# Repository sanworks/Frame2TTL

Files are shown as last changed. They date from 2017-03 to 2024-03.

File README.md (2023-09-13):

# Frame2TTL
Hardware and software to capture discrete pixel intensity transitions from a small patch of an LCD screen. Transitions are reported as TTL pulses. This device is used to provide precise measurements of frame onset time in visual stimulus presentation

The bill of materials and other documentation is available at:
https://sites.google.com/site/frame2ttl

Frame2TTL is a product of Sanworks LLC, licensed under GPL v3.0 (see included license)
http://sanworks.io

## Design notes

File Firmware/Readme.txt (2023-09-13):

To compile for Frame2TTL v2 and newer, use the firmware in the Frame2TTL folder.
Configure the HARDWARE_VERSION macro to match your hardware version.

For Frame2TTL v1, use firmware in the Legacy folder.

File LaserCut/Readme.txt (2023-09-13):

Note: To be laser cut from 3mm clear acrylic sheet.

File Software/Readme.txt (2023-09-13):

Important note:
For Frame2TTL hardware v1, use software in the Legacy folder.

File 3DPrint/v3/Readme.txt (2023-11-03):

Build notes:

F2TTL_v3_PrintedParts_r1_0 and
F2TTL_v3_PrintedParts_r1_0_PressFitSensor
are designed for 3D-printing on an FDM machine.

In the PressFitSensor version, the sensor connects to the side mount arm with a loose friction fit instead of with tab locking, allowing it to be removed after assembly.

Material: Ultimaker CPE, ColorFabb XT or equivalent
Material color: Black
Nozzle width: 0.4mm
Ultimaker printer recommended. Use slicer settings from included Cura profile.

F2TTL_v3 contains 4 parts to print, and 1 model of the circuit board (colored black). Part names are noted in the design file.

Assembly notes:
-The PCB mount holds the sensor PCB. Press the PCB bottom into the bottom of the mount and bend the mount slightly until the PCB presses under the retaining edges. The PCB will be secure when the mount relaxes.

-The PCB mount snaps into the side arm with moderate pressure. Orient the PCB mount so that the sensor faces towards the arm.

-The rear arm has a socket for a captured nut and thumb screw. The rectangular extension of the side arm fits into the rectangular hole in the rear arm. The initial fit may be tight. Force the rear arm back and forth along the side arm ~20 times to achieve a good fit.

-The foot connects to the rear arm with the dowel pin. Align the holes and press the dowel pin from above until it mates with the narrow hole on the opposite side, securing the foot in place.

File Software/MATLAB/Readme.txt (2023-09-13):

IMPORTANT NOTE:
The Frame2TTL class in this folder supports hardware v2 or newer.
A class compatible with hardware v1 can be found in /Software/Legacy/

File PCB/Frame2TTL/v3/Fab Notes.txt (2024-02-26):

-Frame2TTL_v3_X_Sensor must be fabbed with board thickness = 0.6mm
-Frame2TTL_v3_X must be fabbed with board thickness = 1.6mm (standard)

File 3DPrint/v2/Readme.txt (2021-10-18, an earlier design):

Files are designed for 3D-printing on an FDM machine

Material: CPE, ColorFabb XT or equivalent
Nozzle width: 0.4mm
Ultimaker printer recommended. Use slicer settings from included Cura profile.

F2TTL_v2_ForIpad contains 2 parts to print, and 1 model of the board. The two parts press together to form a clip that gently mounts the sensor to the bottom edge of an Ipad screen (Adafruit Part# 1751). The first part must be slightly bent to insert the circuit board. Then, the first part presses into the second part.

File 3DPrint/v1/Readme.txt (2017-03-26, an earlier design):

The parts in Frame2TTL.skp should be printed by FDM with a 0.4mm nozzle.
Recommended: 30% infill, 1.6mm wall thickness

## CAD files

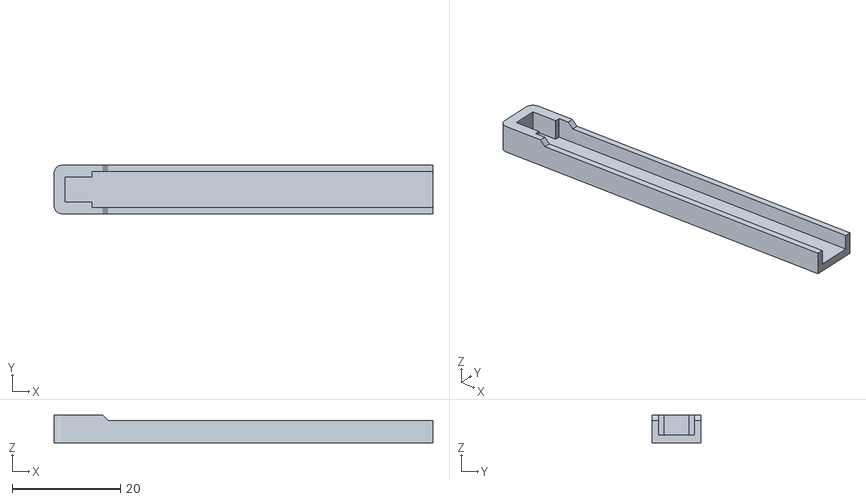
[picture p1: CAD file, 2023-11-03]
Sketchup/Frame2TTL1.stl
70.0 x 9.00 x 5.10

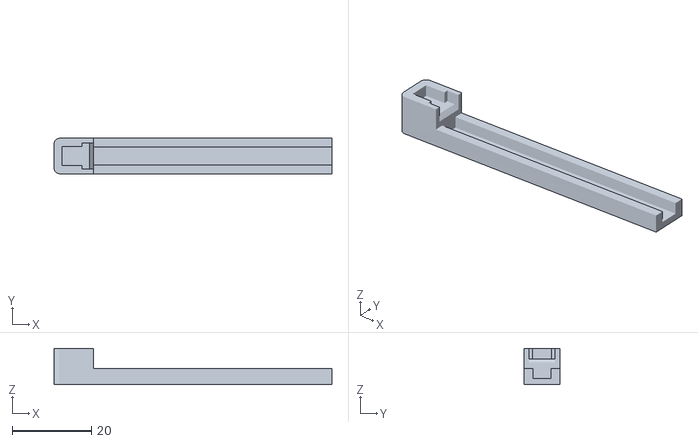
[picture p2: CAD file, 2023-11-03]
Sketchup/Frame2TTL2.stl
70.0 x 9.00 x 9.11

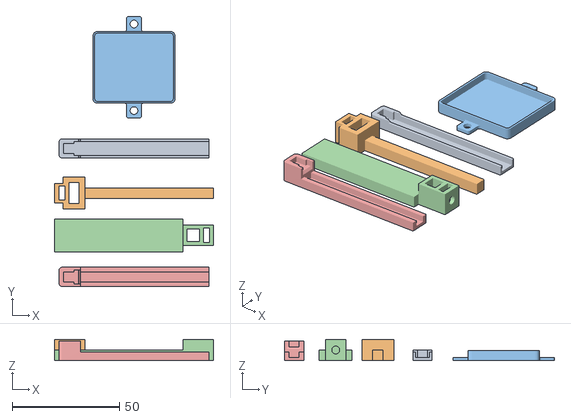
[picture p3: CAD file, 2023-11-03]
Sketchup/Frame2TTLAll.stl
74.3 x 126.0 x 10.0
"Frame2TTLAll" x 5

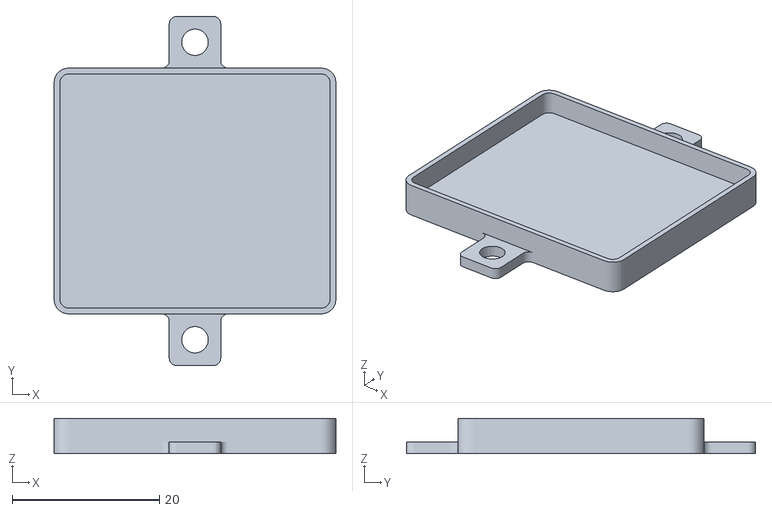
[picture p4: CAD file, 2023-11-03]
Sketchup/Frame2TTL5.stl
38.3 x 47.4 x 4.80

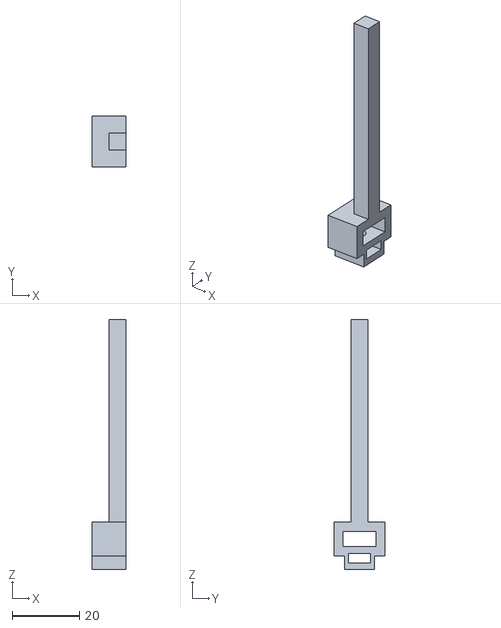
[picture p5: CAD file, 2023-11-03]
Sketchup/Frame2TTL4.stl
10.0 x 15.0 x 74.1

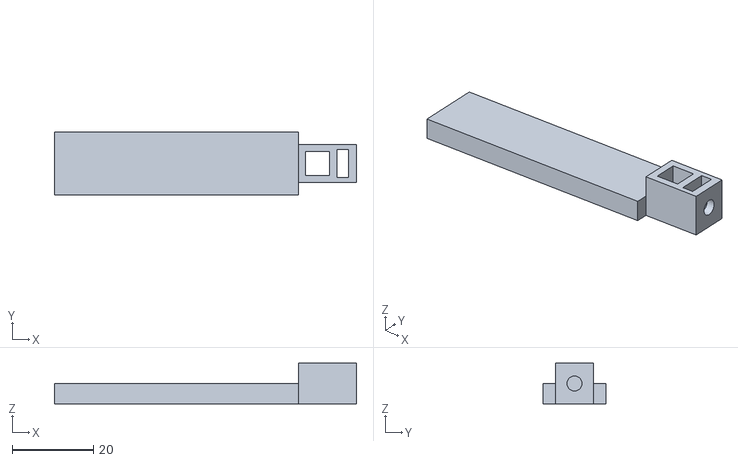
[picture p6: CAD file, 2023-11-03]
Sketchup/Frame2TTL3.stl
74.3 x 15.4 x 10.0

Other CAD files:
3DPrint/v1/Frame2TTL.skp
3DPrint/v1/PCB_UnderGuard.skp
3DPrint/v2/F2TTL_V2_ForIpad.skp
3DPrint/v3/Frame2TTL_v3_PrintedParts_r1_0.skp
3DPrint/v3/Frame2TTL_v3_PrintedParts_r1_0_PressFitSensor.skp
3DPrint/v3/Frame2TTL_v3_PrintedParts_r1_1.skp
LaserCut/Frame2TTL_v3_LaserCutParts_r1_0.skp

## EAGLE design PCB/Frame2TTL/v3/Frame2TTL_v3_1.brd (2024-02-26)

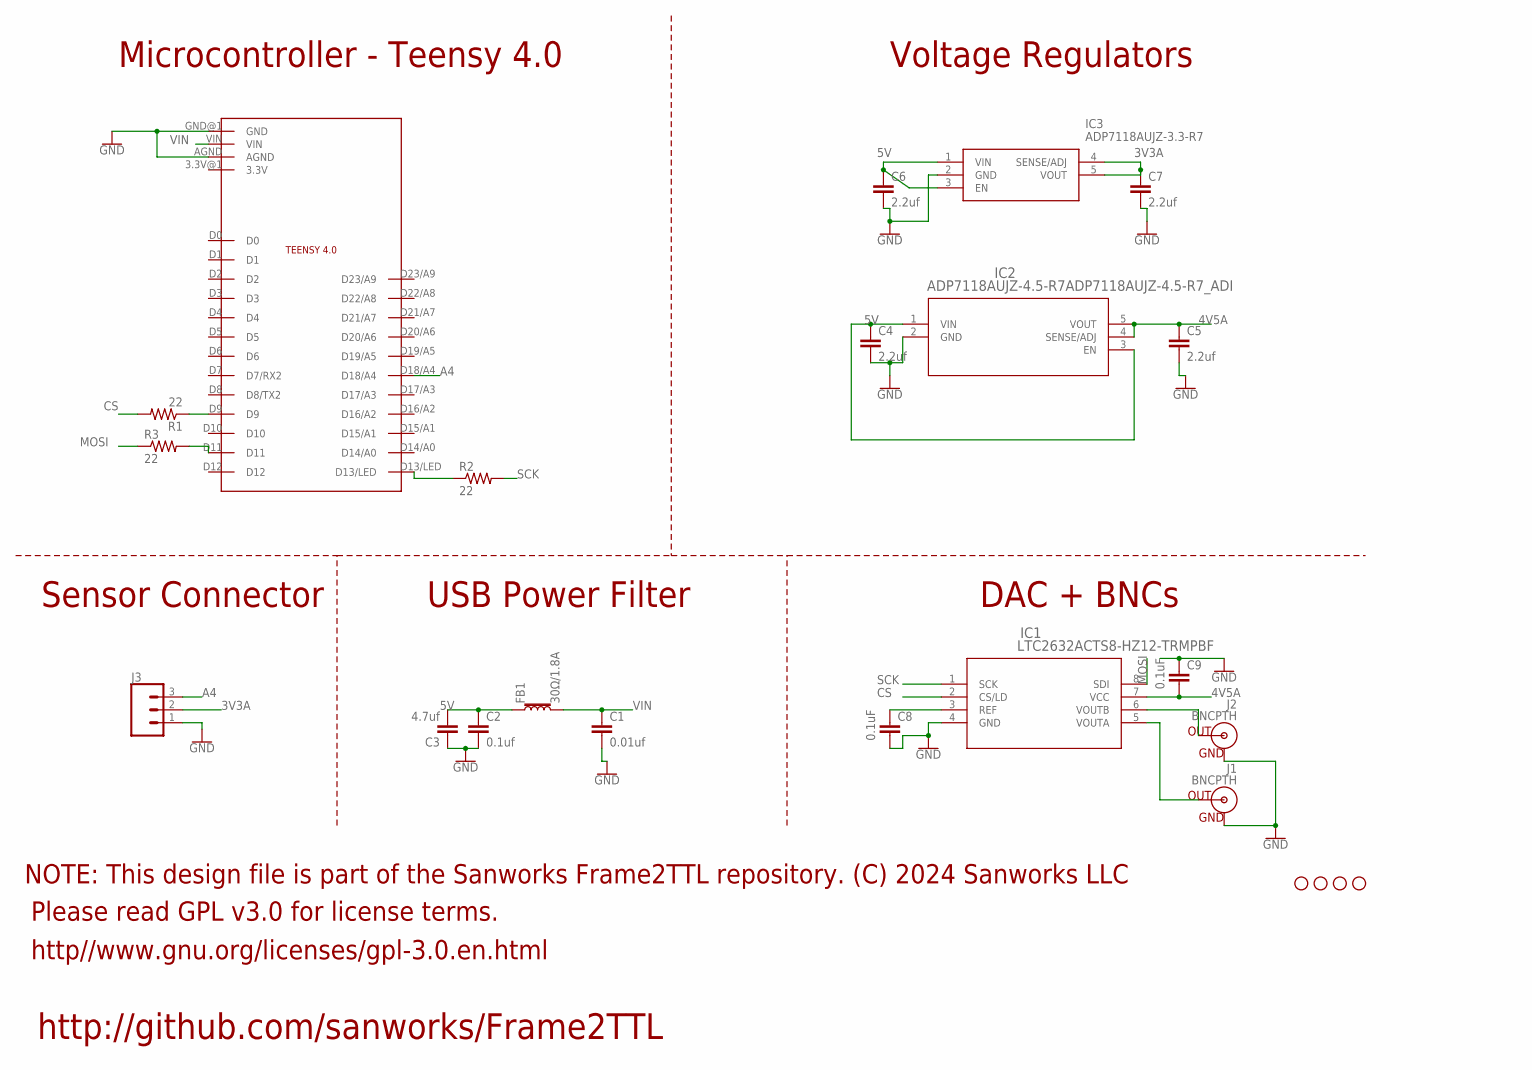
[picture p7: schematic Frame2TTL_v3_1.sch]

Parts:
C1: 0.01uf; 0805
C2: 0.1uf; 0805
C3: 4.7uf; 1206@2
C4, C5, C6, C7: 2.2uf; 0805
C8, C9: 0.1uF; 0805
FB1: 30Ω/1.8A; 0603
H1, H2, H3, H4: STAND-OFF
IC1: LTC2632ACTS8-HZ12-TRMPBF; TSOT-23-8_1P625X2P9_ADI
IC2: ADP7118AUJZ-4.5-R7ADP7118AUJZ-4.5-R7_ADI; ADP7118AUJZ-4.5-R7_ADI
IC3: ADP7118AUJZ-3.3-R7; SOT95P280X100-5N
J1, J2: BNCPTH; BNC
J3: CONN_03LOCK; 1X03_LOCK
MC1: TEENSY4.0_SIMPLE_NO_VUSB
R1, R2, R3: 22; R0805

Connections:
3V3A: C7.1, IC3.4 (SENSE/ADJ), IC3.5 (VOUT), J3.2
4V5A: C5.1, C9.2, IC1.7 (VCC), IC2.4 (SENSE/ADJ), IC2.5 (VOUT)
5V: C2.1, C3.2, C4.1, C6.1, FB1.1, IC2.1 (VIN), IC2.3 (EN), IC3.1 (VIN), IC3.3 (EN)
A4: J3.3, MC1.D18/A4
CS: IC1.2 (CS/LD), R1.2
GND: C1.2, C2.2, C3.1, C4.2, C5.2, C6.2, C7.2, C8.2, C9.1, IC1.4 (GND), IC2.2 (GND), IC3.2 (GND), J1.GND, J2.GND, J3.1, MC1.AGND, MC1.GND@1 (GND)
MOSI: IC1.8 (SDI), R3.1
unnamed: MC1.D11, R3.2
unnamed: MC1.D9, R1.1
unnamed: MC1.D13/LED, R2.1
unnamed: IC1.5 (VOUTA), J1.S (OUT)
unnamed: IC1.6 (VOUTB), J2.S (OUT)
unnamed: C8.1, IC1.3 (REF)
SCK: IC1.1 (SCK), R2.2
VIN: C1.1, FB1.2, MC1.VIN

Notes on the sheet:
Please read GPL v3.0 for license terms.
NOTE: This design file is part of the Sanworks Frame2TTL repository. (C) 2024 Sanworks LLC
http://github.com/sanworks/Frame2TTL
http//www.gnu.org/licenses/gpl-3.0.en.html
Microcontroller - Teensy 4.0
Voltage Regulators
USB Power Filter
Sensor Connector
DAC + BNCs

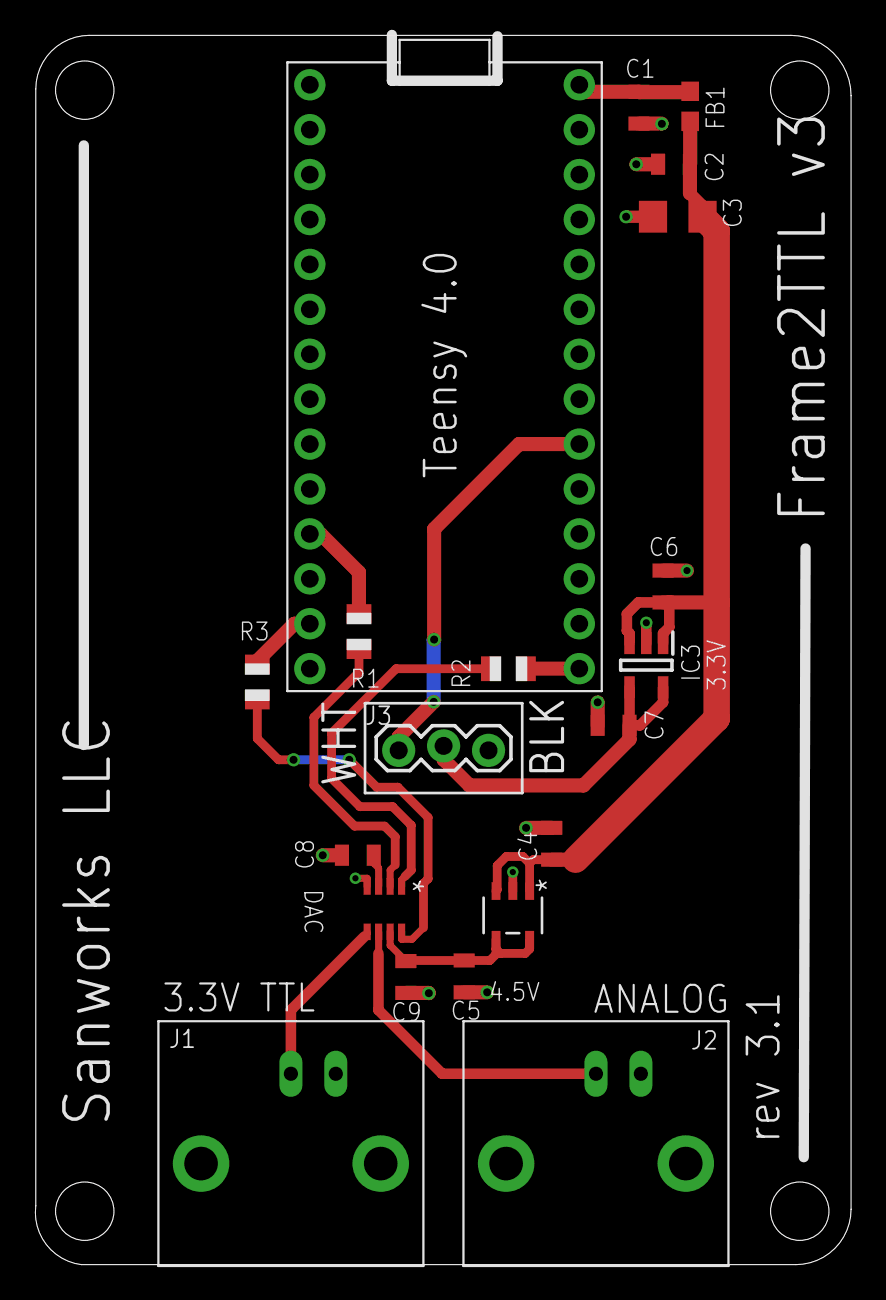
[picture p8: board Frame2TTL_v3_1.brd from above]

Board: 2 copper layers, 46.1 x 69.5 mm, 24 parts (0 on the bottom side), 15 nets.

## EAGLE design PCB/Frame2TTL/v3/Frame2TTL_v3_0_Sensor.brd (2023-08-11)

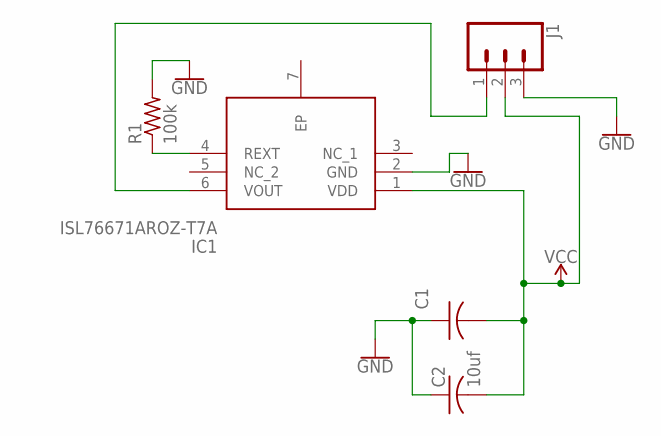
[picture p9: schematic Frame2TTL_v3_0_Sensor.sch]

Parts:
C1: 0.1uf; C0603K
C2: 10uf; C0805K
IC1: ISL76671AROZ-T7A; SON65P210X200X80-7N
J1: CONN_03LOCK; 1X03_LOCK
R1: 100k; R0805

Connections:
GND: C1.1, C2.1, IC1.2 (GND), J1.3, R1.2
unnamed: IC1.6 (VOUT), J1.1
unnamed: IC1.4 (REXT), R1.1
VCC: C1.2, C2.2, IC1.1 (VDD), J1.2

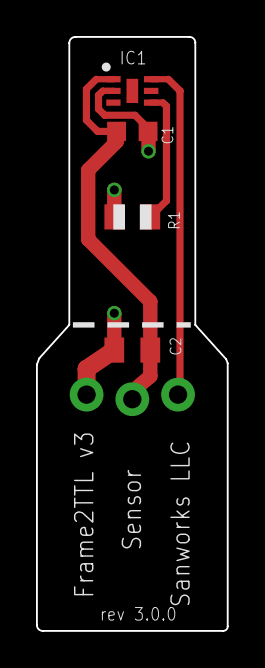
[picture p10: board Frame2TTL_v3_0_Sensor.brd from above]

Board: 2 copper layers, 10.6 x 33.0 mm, 5 parts (1 on the bottom side), 4 nets.

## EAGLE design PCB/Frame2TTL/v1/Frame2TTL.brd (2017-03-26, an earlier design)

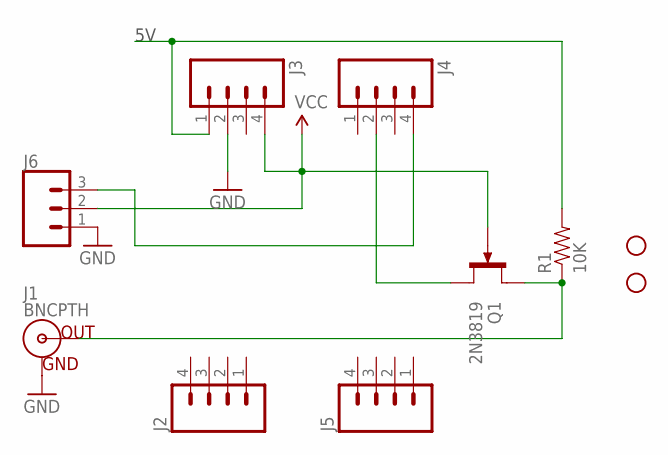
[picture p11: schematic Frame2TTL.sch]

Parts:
H1, H2: STAND-OFFTIGHT; STAND-OFF-TIGHT
J1: BNCPTH; BNC
J2, J3, J4, J5: M04PTH; 1X04
J6: CONN_03SCREW_LOCK; SCREWTERMINAL-3.5MM-3_LOCK.007S
Q1: 2N3819; TO92F
R1: 10K; AXIAL-0.3

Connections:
5V: J3.1, R1.P$2 (2)
GND: J1.GND, J3.2, J6.1
unnamed: J4.4, J6.3
unnamed: J4.2, Q1.S
unnamed: J1.S (OUT), Q1.D, R1.P$1 (1)
VCC: J3.4, J6.2, Q1.G

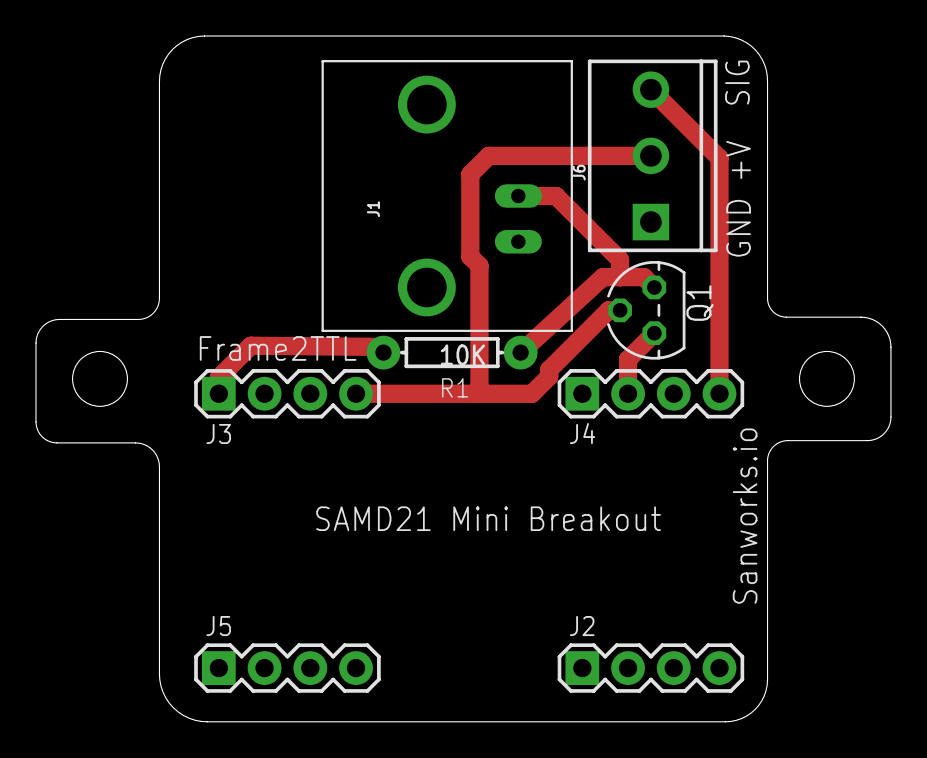
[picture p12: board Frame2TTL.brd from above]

Board: 2 copper layers, 47.5 x 38.1 mm, 10 parts (0 on the bottom side), 6 nets.

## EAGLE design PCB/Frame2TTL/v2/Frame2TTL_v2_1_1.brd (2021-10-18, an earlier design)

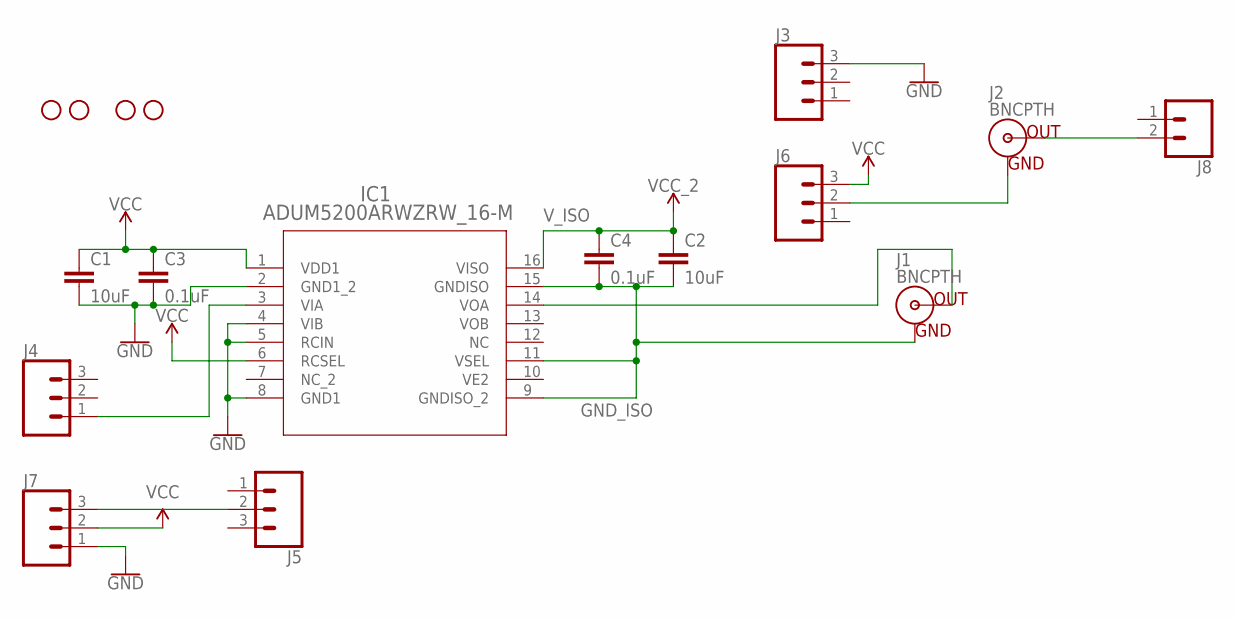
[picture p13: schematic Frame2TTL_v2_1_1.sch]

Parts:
C1, C2: 10uF; 1206
C3, C4: 0.1uF; 0805
H1, H2, H3, H4: STAND-OFF
IC1: ADUM5200ARWZRW_16-M; RW_16-M
J1, J2: BNCPTH; BNC
J3, J4, J5, J6, J7: CONN_03LOCK; 1X03_LOCK
J8: CONN_02; 1X02

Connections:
AGND: J2.GND, J6.2
GND: C1.2, C3.2, IC1.2 (GND1_2), IC1.4 (VIB), IC1.5 (RCIN), IC1.8 (GND1), J3.3, J7.1
GND_ISO: C2.2, C4.2, IC1.9 (GNDISO_2), IC1.11 (VSEL), IC1.15 (GNDISO), J1.GND
unnamed: J2.S (OUT), J8.2
unnamed: IC1.3 (VIA), J4.1
unnamed: J5.2, J7.3
unnamed: IC1.14 (VOA), J1.S (OUT)
VCC: C1.1, C3.1, IC1.1 (VDD1), IC1.6 (RCSEL), J6.3, J7.2
V_ISO: C2.1, C4.1, IC1.16 (VISO)

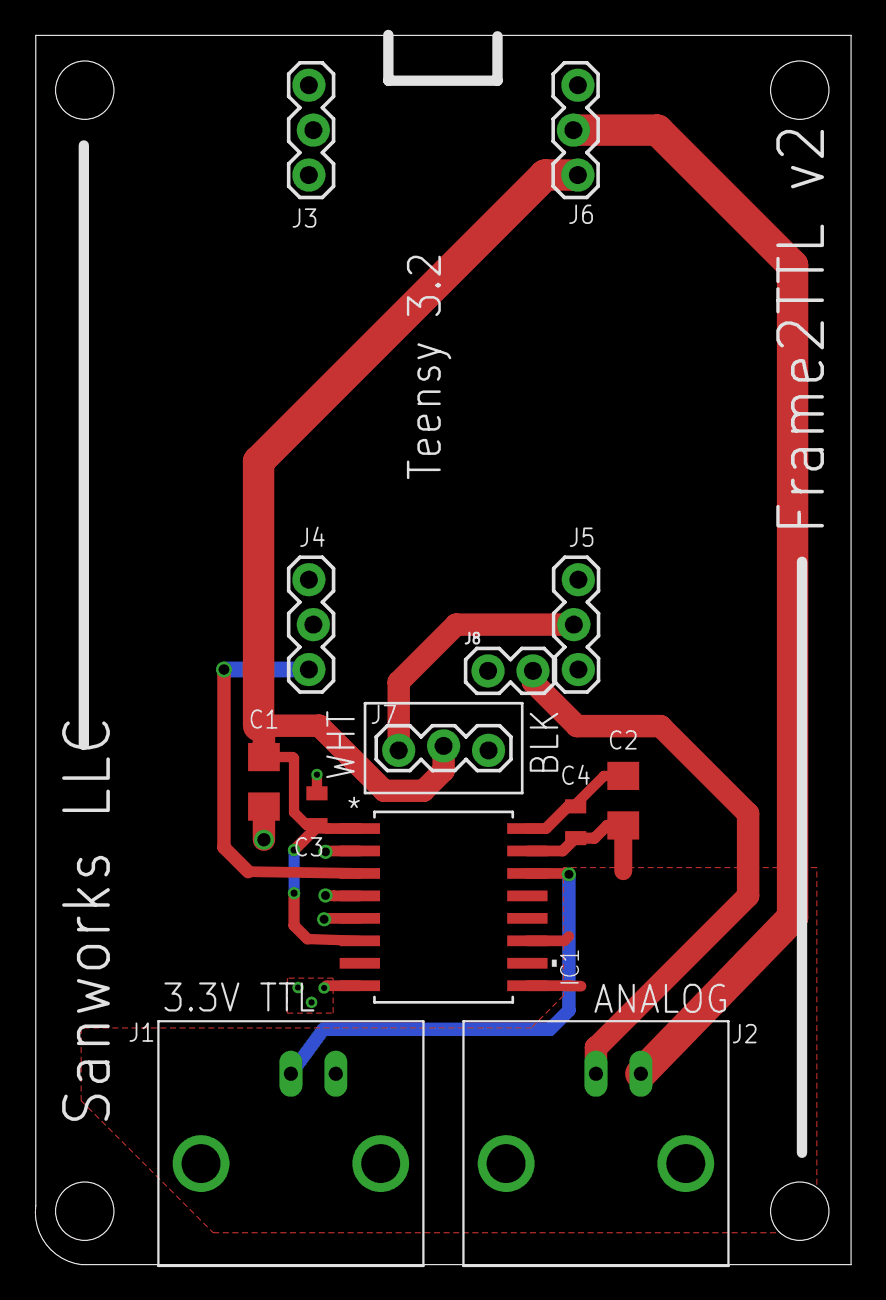
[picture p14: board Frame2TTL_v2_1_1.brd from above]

Board: 2 copper layers, 46.1 x 69.5 mm, 17 parts (0 on the bottom side), 9 nets.

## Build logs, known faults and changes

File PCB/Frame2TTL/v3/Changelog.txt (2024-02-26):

v3.1:
-Resized BNC mounting holes for better alignment

v3.0: 
Initial release

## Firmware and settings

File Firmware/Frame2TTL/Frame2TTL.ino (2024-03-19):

/*
  ----------------------------------------------------------------------------

  This file is part of the Sanworks Frame2TTL repository
  Copyright (C) 2023 Sanworks LLC, Rochester, New York, USA

  ----------------------------------------------------------------------------

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
*/

#include "ArCOM.h"
#include <SPI.h>

// SETUP MACROS TO COMPILE FOR TARGET DEVICE:
#define HARDWARE_VERSION 0 // IMPORTANT! Set this to 2 or 3 to match your hardware. DO NOT set to 1. Use the 'Legacy' firmware file for hardware v1.
// ------------------------------------------

#define FIRMWARE_VERSION 4

ArCOM USBCOM(Serial); // Wrap Serial interface with ArCOM (for easy transmission of different data types)

IntervalTimer hwTimer; // A hardware timer peripheral is used to achieve even sampling

// I/O pins
#if HARDWARE_VERSION == 2
  #define TTL_OUTPUT_LINE 12
#elif HARDWARE_VERSION == 3
  #define DAC_CS_PIN 9
#else
  #error Error! HARDWARE_VERSION must be either 2 or 3. HARDWARE_VERSION 1 requires the legacy firmware.
#endif

// Params
const uint32_t samplingRate = 20000; // Analog sampling rate (Hz)
const uint16_t windowSize = 20; // Number of analog samples to consider for edge detection

// Program Variables
uint32_t currentTime = 0; // Current time (us)
uint32_t lastStreamingSampleTime = 0; // Last time sensor value was sent while streaming
uint32_t streamSampleInterval = 1000; // Interval between samples while streaming, units = us (Hard coded to 1k us = 1000Hz)
volatile uint16_t sensorValue = 0; // Analog value read from sensor
uint32_t analogOutputValue = 0; // Analog output voltage proprotional to light signal
const uint32_t streamingBufferNsamples = 10;
uint16_t sampleBuffer[windowSize] = {0}; // Buffer of light samples used to calculate sliding window average of luminance changes
uint16_t streamingBuffer[streamingBufferNsamples] = {0}; // Buffer of light samples to stream to the PC
uint32_t nSamplesToRead = 0; // For use when relaying a fixed number of contiguous samples to PC
uint32_t nSamplesAdded = 0; // For USB Streaming
int32_t total = 0; // For computing sliding window average
volatile int16_t avgLightDiff = 0; // Sliding window average of sample-wise changes in light intensity
int32_t lightThresh = 75; // Average change in luminance necessary to transition to "inPulse" state
int32_t darkThresh = -75; // Average change in luminance necessary to transition from "inPulse" state
volatile int32_t lightMeasure2Threshold = 0; // Measurement of light to compare against threshold for detection
uint8_t detectMode = 1; // Frame transition detect mode. 0 = absolute luminance. 1 = sliding window average of sample-wise change in luminance. 
int32_t lightActivationThresh = 0; // Threshold for activation of the light threshold in detectMode 0
int32_t darkActivationThresh = 0; // Threshold for activation of the dark threshold in detectMode 0
uint32_t activationMargin = 1000; // Number of bits beyond each threshold for threshold activation in detectMode 0

// State Variables
boolean inPulse = false; // True if the output sync line is high
boolean thresholdActive = false; // True if the threshold is active
boolean isStreaming = false; // True if streaming output to MATLAB
volatile boolean sampleReadyFlag = false; // True if a sample has been read

// Communication variables
byte op = 0; // Operation code from PC

// DAC variables (v3 only)
SPISettings DACSettings(30000000, MSBFIRST, SPI_MODE0); // Settings for DAC
byte dacBuffer[3] = {0}; // Holds bytes to be written to the DAC
union {
  byte byteArray[4];
  uint16_t uint16[2];
} dacValue; // This structure allows for very efficient type casting


void setup() {
  SPI.begin(); // Initialize SPI bus (for communication with DAC)
  #if HARDWARE_VERSION == 2
    analogReadResolution(16); // Set analog reads to 16-bit
    analogWriteResolution(12); // Set analog writes to 12-bit
    pinMode(TTL_OUTPUT_LINE, OUTPUT);
  #elif HARDWARE_VERSION == 3
    analogReadResolution(12); // Set analog reads to 12-bit
    pinMode(A4, INPUT_DISABLE); // Configure analog input pin to high impedance
    pinMode(DAC_CS_PIN, OUTPUT); // Configure SPI Chip Select pin for DAC
    digitalWrite(DAC_CS_PIN, HIGH);
    SPI.beginTransaction(DACSettings);
    powerUpDAC();
  #endif
  hwTimer.begin(readNewSample, (1/(double)samplingRate)*1000000);  // set readNewSample() to run once per sample
}

void readNewSample() {
  currentTime = micros();

  // Read sensor and update analog output
  
  #if HARDWARE_VERSION == 2
    sensorValue = analogRead(A0);
    analogWrite(A14, sensorValue/16); // Map sensorValue from 16-bit to 12-bit range (0-4096) and write to analog output
  #else
    sensorValue = analogRead(A4)*16;
    dacValue.uint16[1] = sensorValue;
  #endif
  
// Compute avgLightDiff, the sliding window average of sample-wise change in light level
  if (detectMode == 1) {
    memcpy(sampleBuffer, &sampleBuffer[1], sizeof(sampleBuffer)-2);
    sampleBuffer[windowSize-1] = sensorValue;
    total = 0;
    for (int i = 0; i < windowSize-1; i++) {
      total += (sampleBuffer[i+1] - sampleBuffer[i]);
    }
    avgLightDiff = total/windowSize;
    lightMeasure2Threshold = avgLightDiff;
  } else {
    lightMeasure2Threshold = sensorValue;
  }
  
  // Detect light patch transition events and set sync state
  if (inPulse == false) {
    if ((lightMeasure2Threshold > lightThresh) && thresholdActive) {
      inPulse = true;
      if (detectMode == 0) {
        thresholdActive = false;
      }
      #if HARDWARE_VERSION == 2
        digitalWrite(TTL_OUTPUT_LINE, HIGH);
      #endif
      dacValue.uint16[0] = 54067;
    }
    if (lightMeasure2Threshold < lightActivationThresh) {
      thresholdActive = true;
    }
  } else {
    if ((lightMeasure2Threshold < darkThresh) && thresholdActive) {
      inPulse = false;
      if (detectMode == 0) {
        thresholdActive = false;
      }
      #if HARDWARE_VERSION == 2
        digitalWrite(TTL_OUTPUT_LINE, LOW);
      #endif
      dacValue.uint16[0] = 0;
    }
    if (lightMeasure2Threshold > darkActivationThresh) {
      thresholdActive = true;
    }
  }
  #if HARDWARE_VERSION == 3
    dacWrite();
  #endif
  sampleReadyFlag = true;
}

void loop() {
  if (USBCOM.available()) {
    op = USBCOM.readByte();
    switch(op) {
      case 'C': // Confirm USB connection
        USBCOM.writeByte(218);
      break;
      case 'T': // Set Light Threshold (Manual)
        lightThresh = USBCOM.readInt32();
        lightActivationThresh = lightThresh - activationMargin;
      break;
      case 'K': // Set Dark Threshold (Manual)
        darkThresh = USBCOM.readInt32();
        darkActivationThresh = darkThresh + activationMargin;
      break;
      case 'D': // Set Dark Threshold (Automatic; measured with sync patch on to ensure that on -> off transition is below noise)
        darkThresh = autoSetThreshold(0);
        USBCOM.writeInt32(darkThresh);
      break;
      case 'L': // Set Light Threshold (Automatic; measured with sync patch off to ensure that off -> on transition is above noise)
        lightThresh = autoSetThreshold(1);
        USBCOM.writeInt32(lightThresh);
      break;
      case 'M': // Set threshold mode and update thresholds
        detectMode = USBCOM.readByte();
      break;
      case 'G': // Set threshold activation margin (in bits). In detect mode 0, thresholds are inactive until light passes threshold by this margin
        activationMargin = USBCOM.readUint32();
      break;
      case 'S': // Stream sensor value via USB
        isStreaming = USBCOM.readByte();
        nSamplesAdded = 0;
        lastStreamingSampleTime = currentTime;
      break;
      case 'V': // Return contiguous raw sensor values
        nSamplesToRead = USBCOM.readUint32();
        sampleReadyFlag = false;
        for (int i = 0; i < nSamplesToRead; i++) {
          while (sampleReadyFlag == false) {} // Wait for hardware timer to call readNewSample() and update sensorValue
          sampleReadyFlag = false;
          USBCOM.writeUint16(sensorValue);
        }
      break;
      case 'F': // Return firmware version
        USBCOM.writeByte(FIRMWARE_VERSION);
      break;
      case '#': // Return hardware version
        USBCOM.writeByte(HARDWARE_VERSION);
      break;
      case 'Q': // Return sampling rate
        USBCOM.writeUint32(samplingRate);
      break;
    }
  }
  
  if (isStreaming) {
    if ((currentTime - lastStreamingSampleTime) > streamSampleInterval) {
      streamingBuffer[nSamplesAdded] = sensorValue;
      nSamplesAdded++; 
      if (nSamplesAdded == streamingBufferNsamples) {
        USBCOM.writeUint16Array(streamingBuffer, streamingBufferNsamples);
        nSamplesAdded = 0;
      }
      lastStreamingSampleTime = currentTime;
    }
  }
}

uint32_t autoSetThreshold(byte thresholdIndex) { // Measure 1 second of light during a fixed screen state and set a threshold safely outside the noise
  // thresholdIndex = 0 (Light -> Dark threshold) or 1 (Dark -> Light threshold)
  int32_t newThreshold = 0;
  int32_t minValue = 65535;
  int32_t maxValue = -65535;
  uint32_t nSamplesToMeasure = 40000; // 2 seconds at 20kHz
  sampleReadyFlag = false;
  for (int i = 0; i < nSamplesToMeasure; i++) {
    while (sampleReadyFlag == false) {} // Wait for hardware timer to call readNewSample() and update lightMeasure2Threshold
    sampleReadyFlag = false; // Reset flag
    if (lightMeasure2Threshold > maxValue) {
      maxValue = lightMeasure2Threshold;
    }
    if (lightMeasure2Threshold < minValue) {
      minValue = lightMeasure2Threshold;
    }
  }
  switch (thresholdIndex) {
    case 0: // Dark threshold
      newThreshold = minValue*2; // In threshold mode 0: 2x of largest measured negative sliding window average change in light intensity
    break;
    case 1: // Light threshold
      newThreshold = maxValue*2; // In threshold mode 0: 2x of largest measured positive sliding window average change in light intensity
    break;
  }
  return newThreshold;
}

#if HARDWARE_VERSION == 3
  void dacWrite() {
    digitalWriteFast(DAC_CS_PIN,LOW);
    dacBuffer[0] = B00110000; // Channel
    dacBuffer[1] = dacValue.byteArray[1];
    dacBuffer[2] = dacValue.byteArray[0];
    SPI.transfer(dacBuffer,3);
    digitalWriteFast(DAC_CS_PIN,HIGH);
    digitalWriteFast(DAC_CS_PIN,LOW);
    dacBuffer[0] = B00110001; // Channel
    dacBuffer[1] = dacValue.byteArray[3];
    dacBuffer[2] = dacValue.byteArray[2];
    SPI.transfer(dacBuffer,3);
    digitalWriteFast(DAC_CS_PIN,HIGH);
  }

  void powerUpDAC() {
    digitalWriteFast(DAC_CS_PIN,LOW);
    dacBuffer[0] = B01100000; // Enable internal reference
    dacBuffer[1] = 0;
    dacBuffer[2] = 0;
    SPI.transfer(dacBuffer,3);
    digitalWriteFast(DAC_CS_PIN,HIGH);
  }
#endif

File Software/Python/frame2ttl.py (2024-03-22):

"""
----------------------------------------------------------------------------

This file is part of the Sanworks Frame2TTL repository
Copyright (C) Sanworks LLC, Rochester, New York, USA

----------------------------------------------------------------------------

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
----------------------------------------------------------------------------

Frame2TTLv3 is a tool to measure the instant when a PC monitor updates its display.
It uses a light sensor that encodes light intensity as an analog voltage signal.
You can gain intuition for the sensor output using the streamUI() streaming GUI method
below. The light sensor is fixed to a square patch of the display where
a sync signal is rendered by the user. With each successive frame, a "sync patch" of
pixels in the lower-left corner of the screen alternates between black and white.
The sensor detects the white->black and black->white transitions, and outputs
a TTL signal to indicate which patch is currently displayed.

Hardware Installation:
1. Connect the Frame2TTL device to the PC with a USB micro cable.
%. Connect the Frame2TTL device BNC connectors to an oscilloscope for
   testing, or to your acquisition system input for data collection.
3. Fix the Frame2TTL sensor to the bottom-right corner of the screen.
   *IMPORTANT* keep the entire cable at least 5cm away from any AC
   electric lines in the rig, including speaker wires.
   Frame2TTL uses a twisted sensor cable for some EMF resistance, but
   ultimately the sensor signal is analog until it is digitized on the
   circuit board, and is susceptible to EMF along the cable path.

Usage:
Initialize:
F = Frame2TTL('COM3')  # Where COM3 is the Frame2TTL device's usb serial port
F.detect_mode = 1      # Determines how light signal is processed to detect sync patch transitions.
                       # In mode 0, light intensity is compared with a fixed light intensity threshold.
                       # In mode 1, a 1ms sliding window average of sample-wise changes in luminance
                       # is compared with a threshold.
F.dark_threshold = -75 # Set the threshold for detecting a light -> dark sync patch transition.
                       # If detect_mode = 0, units are bits of light intensity
                       # If detect_mode = 1 (default), units are average signed sample-wise change in bits
                       # in a 1ms sliding window. Typical threshold values are in range [-100, 100]
F.set_dark_threshold_auto()  # Automatically set the dark threshold, while the sync patch is
                             # WHITE (standard sensor) or 65% pixel intensity (IBL sensor)
F.set_light_threshold_auto()  # Automatically set the light threshold, while the sync patch is BLACK
sensorValue = F.read_sensor()  # Return the light sensor's current luminance measurement.
                               # Units are bits in range [0, 65535]
sensorValues = F.read_sensor(1000)  # Return 1000 consecutive luminance measurements from the sensor
F.stream_ui() # Launches a live streaming plot of the raw sensor data for diagnostics and to assist with
              # threshold setting in detect_mode 0

Disconnect:
del F

"""

from PyQt5 import QtWidgets, QtCore
from pyqtgraph import AxisItem
import pyqtgraph as pg
import numpy as np
import sys
import time
import math
from arcom import ArCom  # ArCOM wraps PySerial to simplify transactions of numpy data types

# Constants
CURRENT_FIRMWARE = 4
HANDSHAKE_BYTE = 218


class Frame2TTL:
    """Python class to control and read from the Frame2TTL device."""

    def __init__(self, port_name):

        # Create GUI vars
        self.qt_app = None  # for GUI
        self.qt_main = None  # for GUI

        # Connect to hardware
        self.port = ArCom(port_name, 12000000)
        self.port.write(ord('C'), 'uint8')  # Handshake
        reply = self.port.read(1, 'uint8')
        if reply != HANDSHAKE_BYTE:
            raise Frame2TTLError('Error: An incorrect handshake byte was received.')

        # Verify firmware version
        self.port.write(ord('F'), 'uint8')  # Request Firmware version (this op did not exist in firmware v1)
        time.sleep(0.25)  # Wait for a reply. Firmware v1 will return nothing
        old_firmware_found = 0
        if self.port.bytes_available() == 0:
            old_firmware_found = 1
        self._firmware_version = self.port.read(1, 'uint8')
        if old_firmware_found or self._firmware_version < CURRENT_FIRMWARE:
            raise Frame2TTLError('Error: Old Frame2TTL firmware detected. Update to firmware v' +
                                 str(CURRENT_FIRMWARE) + ' or newer.')
        if self._firmware_version > CURRENT_FIRMWARE:
            raise Frame2TTLError('Error: Future Frame2TTL firmware detected. Downgrade to firmware v' +
                                 str(CURRENT_FIRMWARE) + ' or update Frame2TTL software.')

        # Verify hardware version
        self.port.write(ord('#'), 'uint8')  # Request HW version.
        self._hardware_version = self.port.read(1, 'uint8')
        if self._hardware_version == 3:  # For HW 3, reinitialize to full baud rate
            self.port = []
            time.sleep(0.25)
            self.port = ArCom(port_name, 480000000)

        # Set default detection parameters
        self._light_threshold = 75
        self._dark_threshold = -75
        self._activation_margin = 1000
        self._detect_mode = 1

        # Initialize detect mode and thresholds
        self.detect_mode = 1

        # Program the default threshold activation margin (units = bits, used only in detect_mode 0)
        self.port.write(ord('G'), 'uint8', self._activation_margin, 'uint32')

    @property
    def light_threshold(self):
        return self._light_threshold

    @light_threshold.setter
    def light_threshold(self, value):
        if value <= 0 or not isinstance(value, int):
            raise Frame2TTLError('Error: light_threshold must be a positive integer.')
        if self.detect_mode == 0:
            maxThresh = 65535 - self._activation_margin
            if not ((value >= self._activation_margin) and (value <= 65535)):
                raise Frame2TTLError('Error: in detect_mode 0, light_threshold must be in range ['
                                     + str(self._activation_margin) + ', ' + str(maxThresh) + '].')
            if value >= self.dark_threshold:
                raise Frame2TTLError('Error: in detect_mode 0, light_threshold must be lower than dark_threshold.')
        self.port.write(ord('T'), 'uint8', value, 'int32')
        self._light_threshold = value

    @property
    def dark_threshold(self):
        return self._dark_threshold
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

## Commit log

2017-03-26 -Initial Commit
    [Frame2TTL.brd, Frame2TTL.sch, Frame2TTL.skp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]
2017-04-17 -Added 3D printable shield to protect PCB bottom from conductors -Added experimental firmware containing an optional sliding window average filter. Updated MATLAB object to set sliding window #sample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
    [PCB_UnderGuard.skp]
2018-04-19 -Set default thresholds in MATLAB class to match firmware defaults -Removed signal-filtering version of firmware
    [Frame2TTL.skp]
2019-11-01 stl files added for ease of printing
    The STL files were not available, so the Sketchup Files were individually exported (exports erred with random boxes added, so they were cleaned up), and STL's were combined in a good printing orienta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
    [Frame2TTL1.stl, Frame2TTL2.stl, Frame2TTL3.stl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]
2020-01-03 Updated Frame2TTL class to initialize threshold variables with default thresholds
2021-10-18 -Added Frame2TTL v2: CAD, Firmware, MATLAB+Python
    [F2TTL_V2_Enclosure.skp, F2TTL_V2_ForIpad.skp, Frame2TTL.brd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]
2022-01-05 -Updated default dark --> light threshold for Frame2TTL v2. Note: on Ipad screens, the sync patch should be rendered at 50% intensity to avoid saturating the sensor.
    [Frame2TTL_v2.ino, Frame2TTLv2.py]
2023-08-11 -Added code and CAD for Frame2TTL v3.0.0
    [F2TTL_V2_ForIpad.skp, F2TTL_V3_0_0.skp, F2TTL_V3_Enclosure.skp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]
2023-09-13 -Added Python support for Frame2TTL v3 -Updated firmware to compile for v2 or v3 -Reorganized repository
    [F2TTL_FOR_IBL_V3_0_0.skp, F2TTL_Standard_V3_0_0.skp, F2TTL_V3_0_0.skp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]
2023-09-13 -Removed an experimental 3D print file -Renamed 3D print and laser cutting files for clarity
    [F2TTL_Standard_V3_0_0.skp, F2TTL_V3_Enclosure.skp, Frame2TTL_v3_LaserCutParts_r1_0.skp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]
2023-09-13 -Firmware: Fixed a pin assignment bug when compiling for hardware v2
    [Frame2TTL.ino]
2023-09-15 -Frame2TTL v1 Firmware: Added soft reset 50 seconds after PC boot. This circumvents an issue affecting hardware v1, where the USB serial interface is non-reponsive after PC reboot on Win10 -Removed r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
    [Frame2TTL.ino, Frame2TTL_v2.ino]
2023-09-15 -Frame2TTL v1 firmware: Disabled soft reset timer if serial port is opened
    [Frame2TTL.ino]
2023-11-03 -v3 3D-printed parts: Added a design version where the sensor can be removed from the side arm after assembly, by using a friction fit instead of a locking tab.
    [Frame2TTL_v3_PrintedParts_r1_0_PressFitSensor.skp]
2024-02-26 -PCB: Added circuit board revision 3.1, optimizing fit of BNC connector mounts -3D printed parts: r1_1 with optimized press fits -Updated PCB version naming convention
    [Frame2TTL_v3_0.brd, Frame2TTL_v3_0.sch, Frame2TTL_v3_0_Sensor.brd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]
2024-03-19 -Incremented firmware to v4 -Added DetectMode, a parameter to set the frame detection algorithm. In DetectMode 0, the threshold is of a moving average of sample-wise change in luminance. In DetectMod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
2024-03-19 -Reversed order of Detect-Mode values. 0 = luminance threshold, 1 (default) = sliding window average of sample-wise luminance change
    [Frame2TTL.ino, frame2ttl.py]
2024-03-19 -Added a safety margin to DetectMode 0. Thresholds are initially inactive, and become active when measured light exceeds threshold by a fixed margin.
    [Frame2TTL.ino, frame2ttl.py]
2024-03-19 -Firmware: Fixed bug where threshold is active on startup
    [Frame2TTL.ino]
2024-03-19 -Fixed bug where setting DetectMode to the current value would overwrite thresholds in MATLAB and Python classes.
    [frame2ttl.py]
2024-03-19 -Python: Restricted Detect Mode 0 on Frame2TTL v2
2024-03-22 -Improved comments, added warning re: cable EMF

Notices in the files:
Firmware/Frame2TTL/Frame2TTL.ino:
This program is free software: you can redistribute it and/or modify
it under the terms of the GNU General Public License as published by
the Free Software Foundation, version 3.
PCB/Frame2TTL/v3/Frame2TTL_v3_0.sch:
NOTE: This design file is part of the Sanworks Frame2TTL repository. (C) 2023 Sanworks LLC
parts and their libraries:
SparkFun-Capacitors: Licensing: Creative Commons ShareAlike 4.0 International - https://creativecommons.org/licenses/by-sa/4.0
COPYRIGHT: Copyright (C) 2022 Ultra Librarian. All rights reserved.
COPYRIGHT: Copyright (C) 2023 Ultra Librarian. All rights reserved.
